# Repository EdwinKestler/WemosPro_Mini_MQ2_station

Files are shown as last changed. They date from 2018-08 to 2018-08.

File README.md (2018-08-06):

# WemosPro_Mini_MQ2_station
Estacion de Temperatura, Humedad y composcion de Aire por medio de sensores HTU y MQ2
## Nodo Sensorial de Temperatura, Humedad, Y compasicion del Aire. 
Este es un nodo sensorial basado en: 
* un sensor HTU21d-f ($15.51 Amazon):
[HTU Amazon](https://www.amazon.com/Adafruit-HTU21D-F-Temperature-Humidity-Breakout/dp/B00OKJFLWO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)
* un sensor de humo MQ2 ($6.99 amazon):
[MQ2 Amazon](https://www.amazon.com/SUKRAGRAHA-Detector-Module-Arduino-Genuino/dp/B01F2X3VY6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)
* un modulo ESP866 (WEMOSD1 MINI pro, $9.99 Amazon):
[WEMOS Amazon](https://www.amazon.com/Aideepen-WEMOS-Mini-Pro-Connector/dp/B07333L9VR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)
* un modulo de manejo de energia y carga solar (Li-po Rider v1.1 seeedstudio, $15.01 Amazon)
[Harvesting Amazon](https://www.amazon.com/Aideepen-WEMOS-Mini-Pro-Connector/dp/B07333L9VR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)
* un Panel Solar de 5V 500mA 2.5W ($15.99 Amazon)
[Panel Amazon](https://www.amazon.com/ALLPOWERS-Battery-Charger-Encapsulated-130x150mm/dp/B074TYH68Z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)
* una Bateria Lipo de 3,000 mah 3.7V ($11.49 Amazon)
[Batteria Amazon](https://www.amazon.com/YDL-3000mAh-battery-Rechargeable-Connector/dp/B07BTV1SCB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)
* una caja plastica IP55 para exteriores ($7.5 Amazon)
[Caja Exteriores Amazon](https://www.amazon.com/LeMotech-Dustproof-Waterproof-Electrical-85mmx85mmx50mm/dp/B075X14RVH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)
* Ultracapacitores 2.8 15F Vishay y diodo (x3 $5.82 Mouser):
[Solar Harvesting](https://www.mouser.com/ProductDetail/Vishay-BC-Components/MAL219691252E3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)
* Alambre de amarre y otros compenetes discretos ($5 varios locales)
* una caja plastica tensparente pequeña (set de 100 piezas $14.99 amazon).
[cajas para Oled y sensor HTU](https://www.amazon.com/Plastic-Empty-Watercolour-100Pcs-Transparent/dp/B07CF7PQFQ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)

# Total costo:  $119.93

### esquematicos
* EagleCad 9.1.2:
    * Schematic:
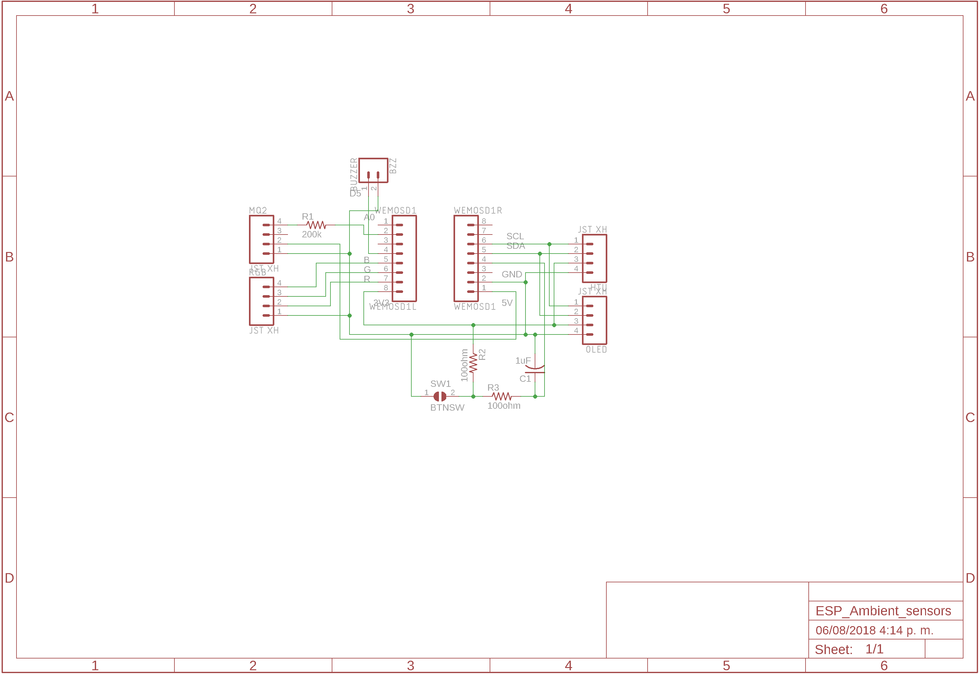
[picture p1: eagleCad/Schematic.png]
    
    * Board:
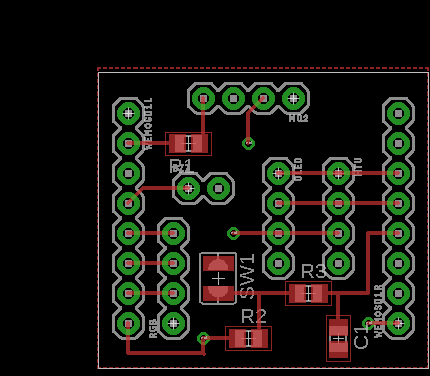
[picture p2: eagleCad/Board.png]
    
* link para pedido en OSHPARK:
[OSHPARK](https://oshpark.com/shared_projects/FCERSQkG)
* Imagenes de Board:
    * Top:
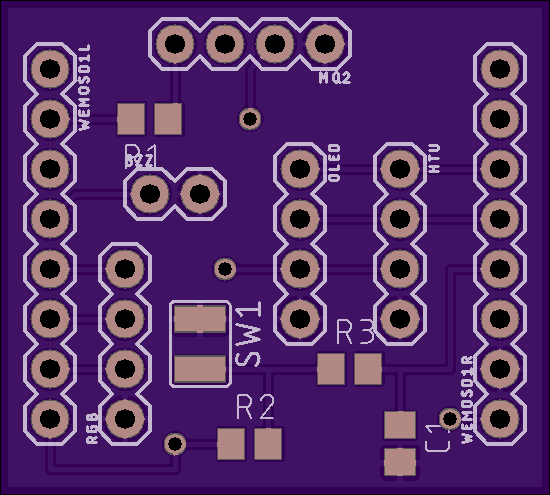
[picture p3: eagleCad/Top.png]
    
    * Botom:
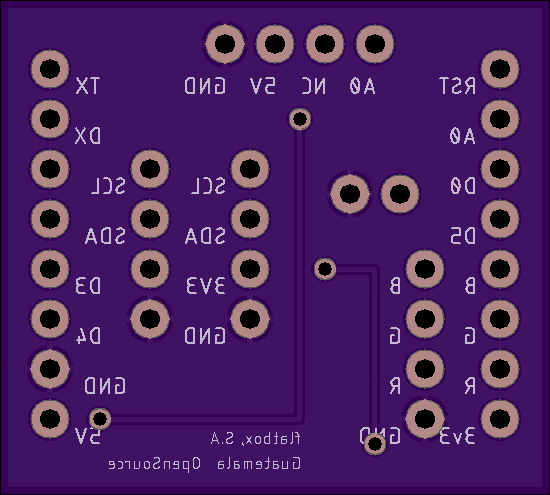
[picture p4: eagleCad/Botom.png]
    
### Fotografias
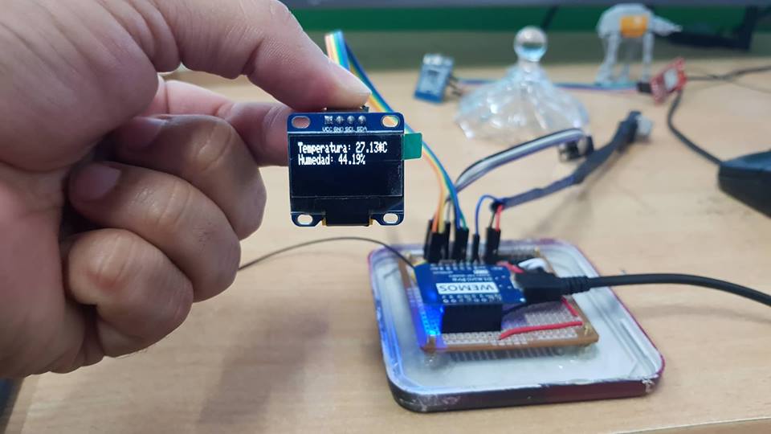
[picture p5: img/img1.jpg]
imagen de construccion de nodo

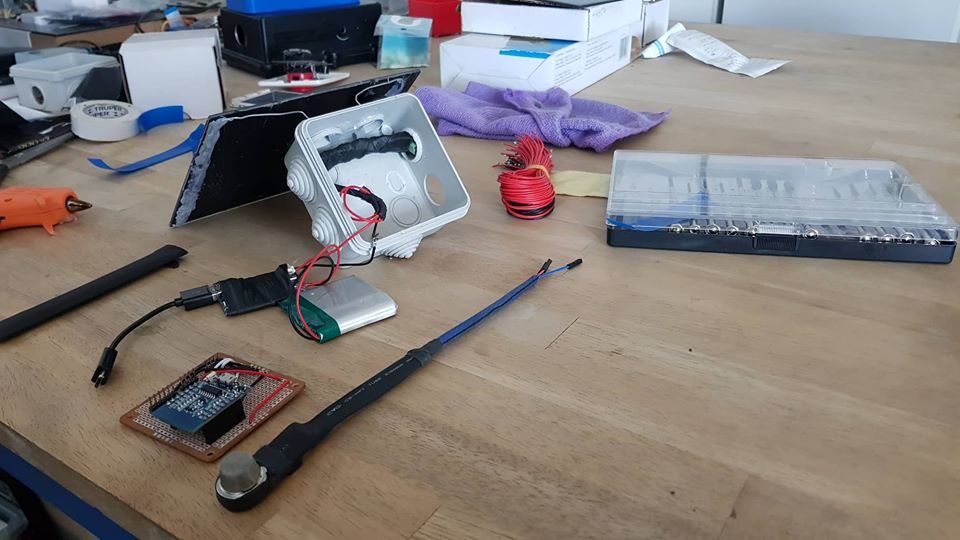
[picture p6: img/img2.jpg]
imagen2 de construccion de nodo

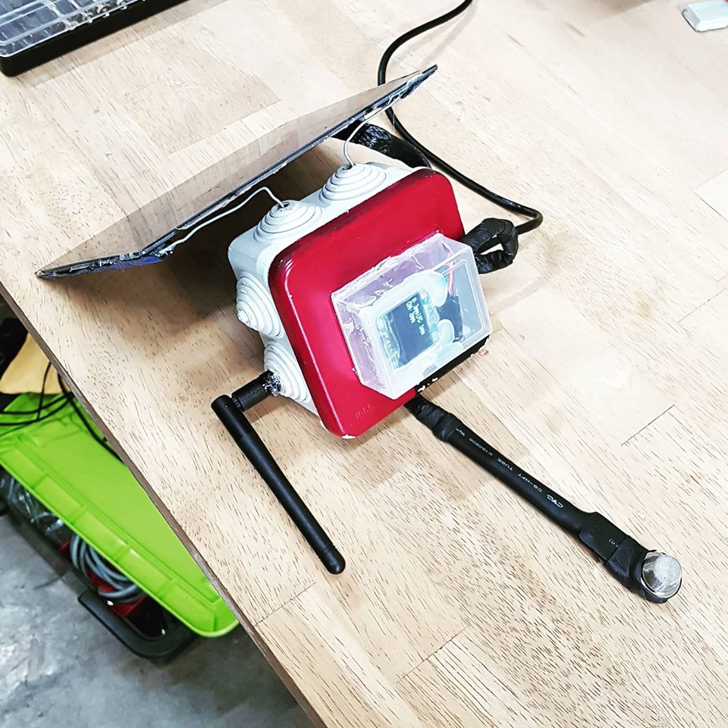
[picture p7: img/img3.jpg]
imagen3 de construccion de nodo

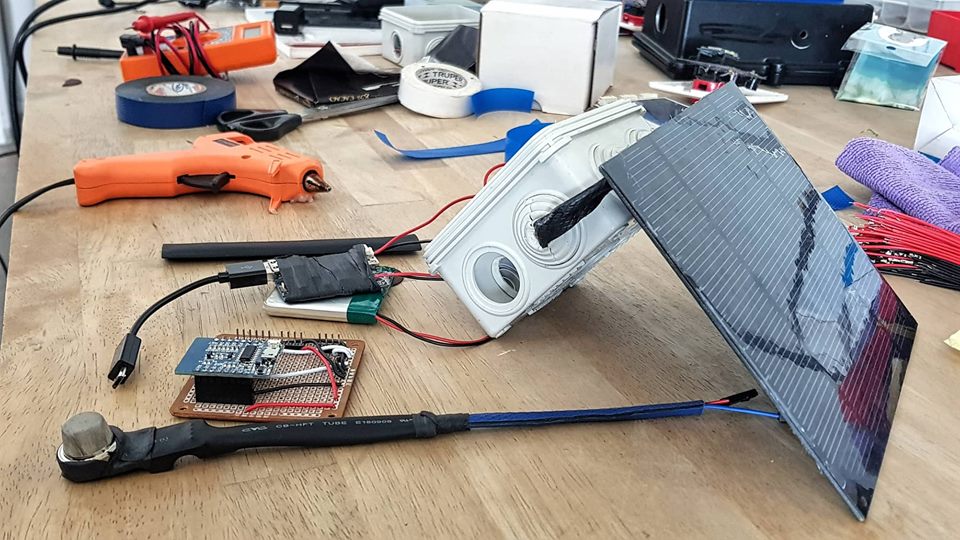
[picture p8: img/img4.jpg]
imagen4 de construccion de nodo

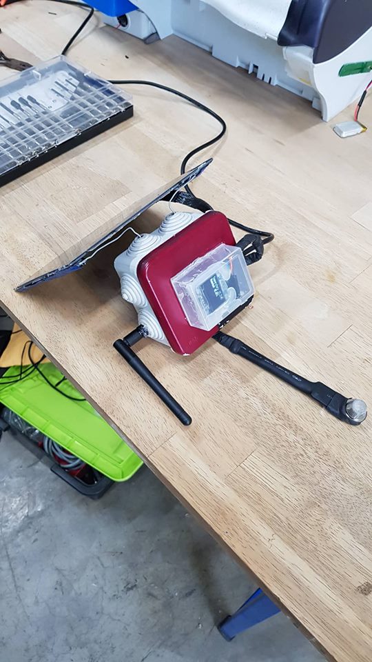
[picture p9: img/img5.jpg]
imagen5 de construccion de nodo

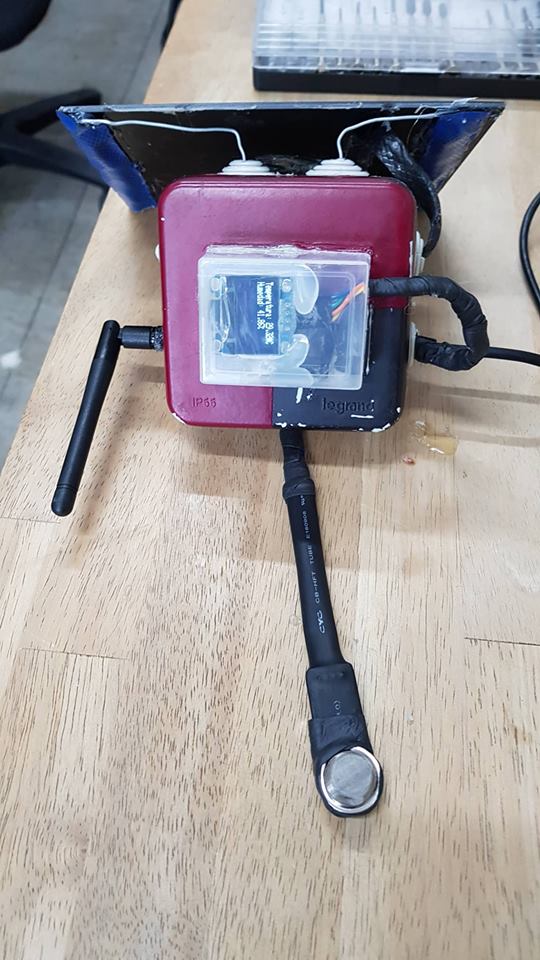
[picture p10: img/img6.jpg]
imagen6 de construccion de nodo


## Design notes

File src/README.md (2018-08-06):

# Nodo Sensorial de Temperatura, Humedad, Y compasicion del Aire. 
Este es un nodo sensorial utilizando und WEMOS D1 MINI R2:
* un sensor I2C HTU puerto  (D1, D2) SCL, SDA;
* un sensor ANALOGO MQ2 Pueto A0 a 3.3V;
* un modulo I2C OLED de 32 direcion 0x33;
* un modulo RGB en los puesrtos (D8,D7,D6) R, G, B; 
* un Buzzer en el puerto (D5);

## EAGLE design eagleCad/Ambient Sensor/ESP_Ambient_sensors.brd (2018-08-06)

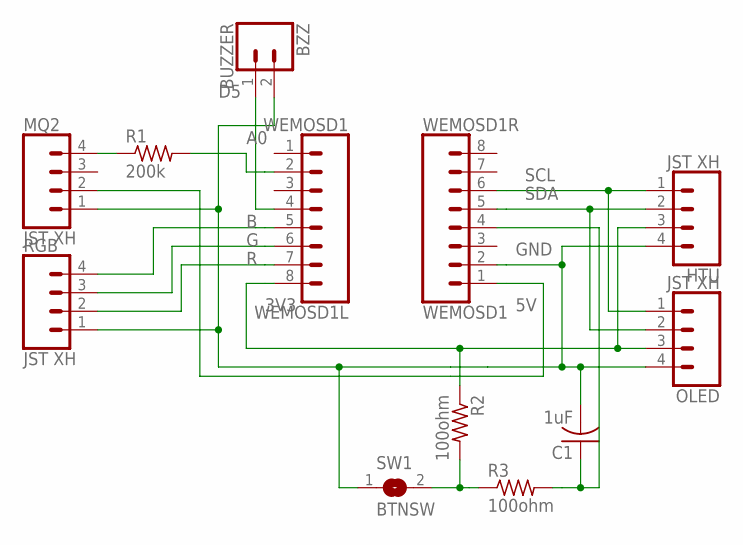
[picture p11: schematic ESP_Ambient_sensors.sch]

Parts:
BZZ: BUZZER; 1X02
C1: 1uF; C0805
HTU: JST XH; 1X04
MQ2: JST XH; 1X04
OLED: JST XH; 1X04
R1: 200k; R0805
R2, R3: 100ohm; R0805
RGB: JST XH; 1X04
SW1: BTNSW; SJW
WEMOSD1L, WEMOSD1R: WEMOSD1; 1X08

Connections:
3V3: HTU.3, OLED.3, R2.1, WEMOSD1L.8
5V: MQ2.2, WEMOSD1R.1
A0: R1.2, WEMOSD1L.2
B: RGB.4, WEMOSD1L.5
D5: BZZ.1, WEMOSD1L.4
G: RGB.3, WEMOSD1L.6
GND: BZZ.2, C1.2, HTU.4, MQ2.1, OLED.4, RGB.1, SW1.1, WEMOSD1R.2
unnamed: R2.2, R3.1, SW1.2
unnamed: C1.1, R3.2, WEMOSD1R.4
unnamed: MQ2.4, R1.1
R: RGB.2, WEMOSD1L.7
SCL: HTU.1, OLED.1, WEMOSD1R.6
SDA: HTU.2, OLED.2, WEMOSD1R.5

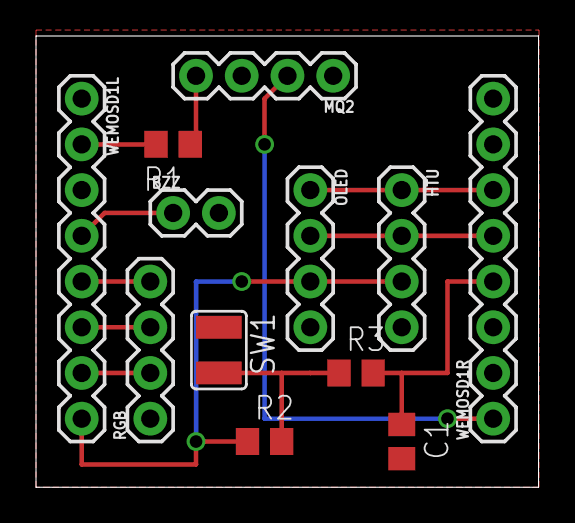
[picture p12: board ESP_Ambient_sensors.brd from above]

Board: 2 copper layers, 27.9 x 25.1 mm, 12 parts (0 on the bottom side), 13 nets.

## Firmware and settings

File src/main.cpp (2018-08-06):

/*
  Remote smoke detection and emviroment node.
  Created by Edwin Kestler, May 29, 2018.
  Released into the public domain.
   MITLicense View Settings.h for more info;
  You must keep the attribution on the PCB and schematic and in the firmware files, as is
  released version 1.0 6 agosto 2018
*/
#include <Arduino.h>
// Librerias de ESP // MQTT/ JSON FORMAT data
#include <ESP8266WiFi.h>                                              //Libreira de ESPCORE ARDUINO
#include <PubSubClient.h>                                             //https://github.com/knolleary/pubsubclient/releases/tag/v2.3
#include <ArduinoJson.h>                                              //https://github.com/bblanchon/ArduinoJson/releases/tag/v5.0.7
//----------------------------------------------------------------------librerias de TIEMPO NTP
#include <TimeLibEsp.h>                                                  //TimeTracking
#include <WiFiUdp.h>                                                  //UDP packet handling for NTP request
//----------------------------------------------------------------------Librerias de manejo de setup de redes 
#include <ESP8266WebServer.h>                                         //Libreira de html para ESP8266
#include <DNSServer.h>                                                //Libreria de DNS para resolucion de Nombres
#include <WiFiManager.h>                                              //https://github.com/tzapu/WiFiManager
//----------------------------------------------------------------------Librerias de Codigo de Lectora RFID
#include "settings.h"
//----------------------------------------------------------------------Libreria locales de clases de botron y LEDS
#include "BlinkRGB.h"
//************************************************Inicio general de librerias***********************************
#include <Wire.h>
//************************************************Librerias de Sensores Digitales*******************************
#include "Adafruit_HTU21DF.h"
//************************************************Librerias de Pantalla OLED************************************
#include <Adafruit_GFX.h>
#include <Adafruit_SSD1306.h>
//---------------------------------------------------------------------------------RGB Settings
BlinkRGB Azul (D6);
BlinkRGB Verde (D7);
BlinkRGB Rojo (D8);

BlinkColor Blanco  (D6,D7,D8);
BlinkColor Purpura (D6,D4,D8);
//----------------------------------------------------------------------------------Buzzer Settings
const int beep = D5;
unsigned int count = 0;
String msg = "";
int WifiSignal;
//----------------------------------------------------------------------Variables de verificacion de fallas de capa de conexion con servicio
int failed, sent, published;                                          //Variables de conteo de envios 
//----------------------------------------------------------------------Inicio de cliente UDP
WiFiUDP udp;                                                          //Cliente UDP para WIFI
//----------------------------------------------------------------------Codigo para estblecer el protocolo de tiempo en red NTP
const int NTP_PACKET_SIZE = 48;                                       //NTP time is in the first 48 bytes of message
byte packetBuffer[NTP_PACKET_SIZE];                                   //Buffer to hold incoming & outgoing packets
boolean NTP = false;                                                  //Bandera que establece el estado inicial del valor de NTP
//----------------------------------------------------------------------Variables del servicio de envio de datos MQTT
const char* cserver = "";
//char authMethod[] = "use-token-auth";                                 //Tipo de Autenticacion para el servicio de Bluemix (la calve es unica por cada nodo)
//char token[] = TOKEN;                                                 //Variable donde se almacena el Token provisto por el servicio (ver Settings.h)
char clientId[] = "d:" ORG ":" DEVICE_TYPE ":" DEVICE_ID;             //Variable de Identificacion de Cliente para servicio de MQTT Bluemix 
String  Smacaddrs = "00:00:00:00:00:00";
String  Sipaddrs  = "000.000.000.000";
//----------------------------------------------------------------------Declaracion de Variables Globales (procuar que sean las minimas requeridas.)
int DeviceState = 0;
unsigned long last_State_Update;                                       //Variable para llevar conteo del tiempo desde la ultima publicacion
unsigned long last_NTP_Update;                                       //Variable para llevar conteo del tiempo desde la ultima publicacion  
unsigned long last_Local_Warning;                                         //Variable para llevar conteo del tiempo desde la ultima publicacion
unsigned long time_Normal_Reset;                                       //Variable para llevar conteo del tiempo desde la ultima publicacion 
String ISO8601;                                                       //Variable para almacenar la marca del timepo (timestamp) de acuerdo al formtao ISO8601
int hora = 0;
//----------------------------------------------------------------------Variables Propias del CORE ESP8266 Para la administracion del Modulo
String NodeID = String(ESP.getChipId());                              //Variable Global que contiene la identidad del nodo (ChipID) o numero unico
//----------------------------------------------------------------------Funcion remota para administrar las actulizaciones remotas de las variables configurables desde IBMbluemix
void handleUpdate(byte* payload) {                                    //La Funcion recibe lo que obtenga Payload de la Funcion Callback que vigila el Topico de subcripcion (Subscribe TOPIC)
  StaticJsonBuffer<300> jsonBuffer;                                  //Se establece un Buffer de 1o suficientemente gande para almacenar los menasajes JSON
  JsonObject& root = jsonBuffer.parseObject((char*)payload);          //Se busca la raiz del mensaje Json convirtiendo los Bytes del Payload a Caracteres en el buffer
  if (!root.success()) {                                              //Si no se encuentra el objeto Raiz del Json
    Serial.println(F("ERROR en la Letura del JSON Entrante"));        //Se imprime un mensaje de Error en la lectura del JSON
    return;                                                           //Nos salimos de la funcion
    }                                                                 //se cierra el condicional
  Serial.println(F("handleUpdate payload:"));                         //si se pudo encontrar la raiz del objeto JSON se imprime u mensje
  root.prettyPrintTo(Serial);                                         //y se imprime el mensaje recibido al Serial  
  Serial.println();                                                   //dejamos una linea de pormedio para continuar con los mensajes de debugging
}

//------------------------------------------------------------------------------------denifinir el sonido de bocina
void buzzer() 
{
  digitalWrite(beep, HIGH);
  delay(300);
  digitalWrite(beep, LOW);
  delay(100);
}

//----------------------------------------------------------------------Funcion remota para mandar a dormir el esp despues de enviar un RFID
void handleResponse (byte* payloadrsp) 
{
  StaticJsonBuffer<200> jsonBuffer;                                   //Se establece un Buffer de 1o suficientemente gande para almacenar los menasajes JSON
  JsonObject& root = jsonBuffer.parseObject((char*)payloadrsp);       //Se busca la raiz del mensaje Json convirtiendo los Bytes del Payload a Caracteres en el buffer
  if (!root.success()) 
  {                                              //Si no se encuentra el objeto Raiz del Json
    Serial.println(F("ERROR en la Letura del JSON Entrante"));        //Se imprime un mensaje de Error en la lectura del JSON
    return;                                                           //Nos salimos de la funcion
  }                                                                   //se cierra el condicional
  
  Serial.println(F("handleResponse payload:"));                       //si se pudo encontrar la raiz del objeto JSON se imprime u mensje
  root.printTo(Serial);                                         //y se imprime el mensaje recibido al Serial  
  Serial.println();                                                   //dejamos una linea de pormedio para continuar con los mensajes de debugging
}

//----------------------------------------------------------------------Funcion de vigilancia sobre mensajeria remota desde el servicion de IBM bluemix
void callback(char* topic, byte* payload, unsigned int payloadLength)
{//Esta Funcion vigila los mensajes que se reciben por medio de los Topicos de respuesta;
  Serial.print(F("callback invoked for topic: "));                    //Imprimir un mensaje seÃ±alando sobre que topico se recibio un mensaje
  Serial.println(topic);                                              //Imprimir el Topico
  
  if (strcmp (responseTopic, topic) == 0) 
  {                            //verificar si el topico conicide con el Topico responseTopic[] definido en el archivo settings.h local
    handleResponse(payload);
    //return; // just print of response for now                         //Hacer algo si conicide (o en este caso hacer nada)
  }
  
  if (strcmp (rebootTopic, topic) == 0) {                             //verificar si el topico conicide con el Topico rebootTopic[] definido en el archivo settings.h local
    Serial.println(F("Rebooting..."));                                //imprimir mensaje de Aviso sobre reinicio remoto de unidad.
    ESP.reset();                                                    //Emitir comando de reinicio para ESP8266
  }
  
  if (strcmp (updateTopic, topic) == 0) {                             //verificar si el topico conicide con el Topico updateTopic[] definido en el archivo settings.h local
    handleUpdate(payload);                                            //enviar a la funcion handleUpdate el contenido del mensaje para su parseo.
  } 
}
//----------------------------------------------------------------------definicion de Cliente WIFI para ESP8266 y cliente de publicacion y subcripcion
WiFiClient wifiClient;                                                //Se establece el Cliente Wifi
PubSubClient client(MQTTServer, 1883, callback, wifiClient);              //se establece el Cliente para el servicio MQTT
//----------------------------------------------------------------------Funcion de Conexion a Servicio de MQTT
void mqttConnect() 
{
  if (!!!client.connected()) 
  {                                         //Verificar si el cliente se encunetra conectado al servicio
  Serial.print(F("Reconnecting MQTT client to: "));                    //Si no se encuentra conectado imprimir un mensake de error y de reconexion al servicio
  Serial.println(MQTTServer);                                             //Imprimir la direccion del servidor a donde se esta intentado conectar 
  char charBuf[30];
  String CID (clientId + NodeID); 
  CID.toCharArray(charBuf, 30);  
  #if defined (internetS)
    while (!!!client.connect(charBuf, "user", "password")) 
    {                                //Si no se encuentra conectado al servicio intentar la conexion con las credenciales Clientid, Metodo de autenticacion y el Tokeno password
    Serial.print(F("."));                                             //imprimir una serie de puntos mientras se da la conexion al servicio
    Blanco.CFlash();
    }  
  #else
    while (!!!client.connect(charBuf)) {                                //Si no se encuentra conectado al servicio intentar la conexion con las credenciales Clientid, Metodo de autenticacion y el Tokeno password
    Serial.print(F("."));                                             //imprimir una serie de puntos mientras se da la conexion al servicio
    Blanco.CFlash();
    }  
  #endif  
  Serial.println();                                                   //dejar un espacio en la terminal para diferenciar los mensajes.
 }
}

//----------------------------------------------------------------------Funcion de REConexion a Servicio de MQTT
void MQTTreconnect() {
  int retry = 0;
  // Loop until we're reconnected
  while (!client.connected()) {    
    Serial.print(F("Attempting MQTT connection..."));
    Blanco.CFlash();
    buzzer();
    char charBuf[30];
    String CID (clientId + NodeID);
    CID.toCharArray(charBuf, 30);  
     #if defined (internetS)
     if (client.connect(charBuf, "user", "password")) {
      Serial.println(F("connected"));
     }
     #else
     if (client.connect(charBuf)) {
      Serial.println(F("connected"));
     }
     #endif
     else {
      Purpura.CFlash();
      buzzer();
      Serial.print(F("failed, rc="));
      Serial.print(client.state());
      Serial.print(F(" try again in 3 seconds,"));
      Serial.print(F(" retry #:"));
      Serial.println(retry);
      if (retry > 10){
        ESP.restart();
        retry=0;
      }
      retry++;
      // Wait 3 seconds before retrying
      delay(3000);
    }
  }
}
//************************************************Variables de Pantalla OLED************************************
#define OLED_RESET 0
Adafruit_SSD1306 display(OLED_RESET);
#if (SSD1306_LCDHEIGHT != 32)
#error("Height incorrect, please fix Adafruit_SSD1306.h!");
#endif
bool New_screen_display = true;
//*************************************************Variables de Promedio de datos sensores**********************
#define NUMSAMPLES    10
float HTU_Temp =      0;
float Old_HTU_Temp =  0;
float HTU_Hum =       0;
float Old_HTU_Hum =   0;
//*************************************************VAriables de Sensor I2C HTU**********************************
Adafruit_HTU21DF htu = Adafruit_HTU21DF();
/************************mq2sensor************************************/
#define INTERVAL_READ_GAS         20000
#define INTERVAL_READ_HTU         10000
#define INTERVAL_STATE_UPDATE     60000
#define INTERVAL_NTP_UPDATE       6400000
#define INTERVAL_IOTDATA_UPDATE   30000
#define INTERVAL_NORMAL_RESET     3600000


unsigned long time_Read_Gas;
unsigned long time_IoTDATA_Update;
unsigned long time_Read_HTU;

/************************Hardware Related Macros************************************/
#define         MQ2PIN                       (0)     //define which analog input channel you are going to use
#define         RL_VALUE_MQ2                 (10)    //define the load resistance on the board, in kilo ohms
#define         RO_CLEAN_AIR_FACTOR_MQ2      (9.577) //RO_CLEAR_AIR_FACTOR=(Sensor resistance in clean air)/RO,
                                                     //which is derived from the chart in datasheet

/***********************Software Related Macros************************************/
#define         CALIBARAION_SAMPLE_TIMES     (50)    //define how many samples you are going to take in the calibration phase
#define         CALIBRATION_SAMPLE_INTERVAL  (500)   //define the time interal(in milisecond) between each samples in the
                                                     //cablibration phase
#define         READ_SAMPLE_INTERVAL         (50)    //define how many samples you are going to take in normal operation
#define         READ_SAMPLE_TIMES            (5)     //define the time interal(in milisecond) between each samples in 
                                                     //normal operation

/**********************Application Related Macros**********************************/
#define         GAS_HYDROGEN                  (0)
#define         GAS_LPG                       (1)
#define         GAS_METHANE                   (2)
#define         GAS_CARBON_MONOXIDE           (3)
#define         GAS_ALCOHOL                   (4)
#define         GAS_SMOKE                     (5)
#define         GAS_PROPANE                   (6)
#define         accuracy                      (0)   //for linearcurves
//#define         accuracy                    (1)   //for nonlinearcurves, un comment this line and comment the above line if calculations 
                                                    //are to be done using non linear curve equations
/*****************************Globals************************************************/
float           Ro = 0;                            //Ro is initialized to 10 kilo ohms

volatile int READ_GAS_HYDROGEN =        0;
volatile int READ_GAS_LPG =             0;
volatile int READ_GAS_METHANE =         0;
volatile int READ_GAS_CARBON_MONOXIDE = 0;
volatile int READ_GAS_ALCOHOL =         0;
volatile int READ_GAS_SMOKE =           0;
volatile int READ_GAS_PROPANE =         0;
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
void loop() {
  switch(fsm_state)
  { // inciar el casw switch
    case STATE_IDLE: // hacer cuando el estado sea IDLE
    
     if(millis() > time_Read_HTU + INTERVAL_READ_HTU)
    {
      time_Read_Gas = millis();
      fsm_state = STATE_READ_TEMPERATURE_DATA;  
    }
    
    if(millis() > time_Read_Gas + INTERVAL_READ_GAS)
    {
      time_Read_Gas = millis();
      display.clearDisplay();
      Get_PPM_Compsosition();    
    }

    if(millis() > time_Normal_Reset + INTERVAL_NORMAL_RESET)
    {
      time_Read_Gas = millis();
      NormalReset();    
    }

    if(millis() > last_State_Update + INTERVAL_STATE_UPDATE)
    {
      last_State_Update = millis(); //Actulizar la ultima hora de envio
      fsm_state = STATE_UPDATE;
    }
    
    if(millis() > last_NTP_Update + INTERVAL_NTP_UPDATE) 
    {
      last_NTP_Update = millis(); //Actulizar la ultima hora de envio
      fsm_state = STATE_UPDATE_TIME;
    }

     if(millis() > time_IoTDATA_Update + INTERVAL_IOTDATA_UPDATE) 
    {
      time_IoTDATA_Update = millis(); //Actulizar la ultima hora de envio
      fsm_state = STATE_TRANSMIT_DATA;
    }

    // VERIFICAMOS CUANTAS VECES NO SE HAN ENVIOADO PAQUETES (ERRORES)
    if (failed >= FAILTRESHOLD)
    {
      failed =0;
      published =0;
      sent=0;    
      ESP.restart();
    }
    
    //verificar que el cliente de Conexion al servicio se encuentre conectado
    if (!client.connected()) 
    {
      MQTTreconnect();
    }
    client.loop();
    break;

    case STATE_READ_TEMPERATURE_DATA:                                             //Se verifica la lectura de la temperatura en el htu
    HTU_Temp = get_SensorReading(htu.readTemperature());
    
    if(Old_HTU_Temp != HTU_Temp)
    {
      Old_HTU_Temp = HTU_Temp;
      New_screen_display = true;
    }
    fsm_state = STATE_READ_HUMIDITY_DATA;
    break;

    case STATE_READ_HUMIDITY_DATA:                                                 //Se verifica la lectura del la humedad en el htu
    HTU_Hum =  get_SensorReading(htu.readHumidity());

    if(Old_HTU_Hum != HTU_Hum)
    {
      Old_HTU_Hum = HTU_Temp;
      New_screen_display = true;  
    }

    fsm_state = STATE_UPDATE_UI_SCREEN_HTU;
    break;

    case STATE_UPDATE_UI_SCREEN_HTU:                                                //Se Actuliza la pantalla del Oled si es que hubo un cambio en las lecturas
    
    if(New_screen_display == true)
    {
      New_screen_display = false;
      display.clearDisplay();
      display_Msg_Screen("Humedad: " + String (HTU_Hum) + "%" , 0, 8);
      display_Msg_Screen("Temperatura: " + String (HTU_Temp) + "*C" , 0, 0);
    }

    fsm_state = STATE_IDLE;
    break;
    
    case STATE_TRANSMIT_DATA: //Si se presiono el boton
    //Check connection
    //Send the data
    Serial.println(F("STATE_TRANSMIT_DATA"));
    CheckTime();
    publishRF_Boton(NodeID, HTU_Temp, HTU_Hum, READ_GAS_HYDROGEN, READ_GAS_LPG, READ_GAS_METHANE, READ_GAS_CARBON_MONOXIDE, READ_GAS_ALCOHOL, READ_GAS_SMOKE, READ_GAS_PROPANE  ,ISO8601);  // publishRF_Boton(String IDModulo, String EventID, String Tstamp)
    fsm_state = STATE_IDLE;
    break; 
    
    case STATE_UPDATE:
    Serial.println(F("STATE_UPDATE"));
    updateDeviceInfo();
    fsm_state = STATE_TRANSMIT_DEVICE_UPDATE;
    break;
    
    case STATE_TRANSMIT_DEVICE_UPDATE:
    Serial.println(F("STATE_TRANSMIT_DEVICE_UPDATE"));
    //verificar que el cliente de Conexion al servicio se encuentre conectado
    if (!client.connected())
    {
      MQTTreconnect();
    }
    //verificar la hora
    CheckTime();
    publishRF_ID_Manejo(NodeID, msg, WifiSignal, published, failed, ISO8601, Smacaddrs, Sipaddrs);
    fsm_state = STATE_IDLE;
    break;
    
    case STATE_TRANSMIT_ALARM_UPDATE:
     Serial.println(F("STATE_TRANSMIT_ALARM_UPDATE"));
     //verificar que el cliente de Conexion al servicio se encuentre conectado
     if (!client.connected())
     {
       MQTTreconnect();
     }
     // Verificar la hora
     CheckTime();
     publishRF_ID_Manejo(NodeID,msg, WifiSignal, published, failed, ISO8601, Smacaddrs, Sipaddrs);
    break;
    
    case STATE_UPDATE_TIME:
     Serial.println(F("STATE_UPDATE_TIME"));
     Serial.println(F("Starting UDP"));
     udp.begin(localPort);
     Serial.print(("Local port: "));
     Serial.println(udp.localPort());
     while (NTP == false) 
     {
       setSyncProvider(getNtpTime);                                                          //iniciamos la mensajeria de UDP para consultar la hora en el servicio de NTP remoto (el servidor se configura en 
       delay(UInterval);
     }                                                   //Cuando fue actualizada la hora del reloj
     NTP = false;
     fsm_state = STATE_IDLE; 
    break;
  }
 
  yield();
}

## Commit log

2018-08-03 changed to case states temperture and humidity
2018-08-06 editado el Readme
2018-08-06 se corrigio el markdown
2018-08-06 Cambios de documnentacion
    [ESP_Ambient_sensors.brd, ESP_Ambient_sensors.sch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]
2018-08-06 Actualizacion de Costo

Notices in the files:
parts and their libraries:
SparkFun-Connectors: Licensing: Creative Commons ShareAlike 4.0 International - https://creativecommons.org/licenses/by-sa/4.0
